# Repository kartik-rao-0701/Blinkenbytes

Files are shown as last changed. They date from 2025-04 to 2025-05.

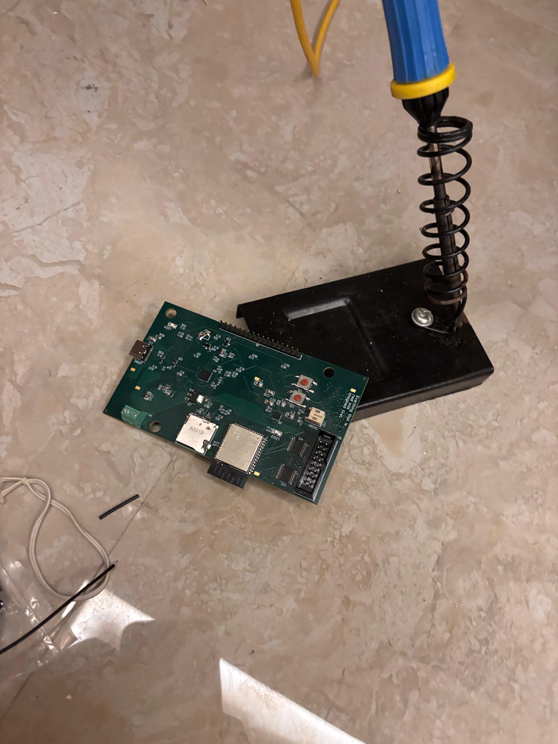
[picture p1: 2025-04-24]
images/pcb after solder.jpg

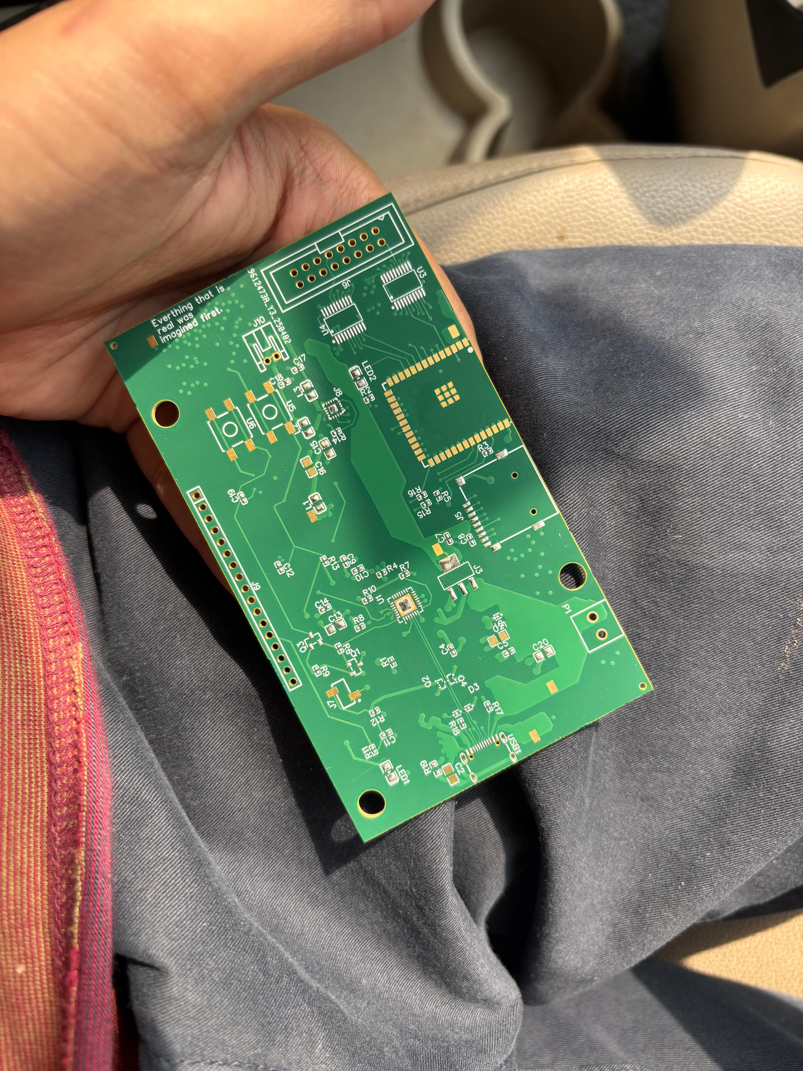
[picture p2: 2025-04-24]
images/pcb recived from jlcpcb(bottom).jpg

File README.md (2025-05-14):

# ESP32-S3 Based Six-Layer Smart Display PCB

This repository contains the design files and documentation for a **custom six-layer PCB** powered by the **ESP32-S3 microcontroller**. The board is designed for advanced **audio-visual applications** with HUB75 LED matrix displays, audio playback, and modern USB-C integration—all packed into a compact, highly optimized board.

---
WhatsApp Image 2025-05-14 at 12 16 19_8cd49088

## 🔧 Key Features

- **ESP32-S3 module** (16MB Flash, 8MB PSRAM *recommended*)
- **Six-layer bare PCB** for enhanced signal stability and thermal performance
- **Onboard microSD card storage** for audio, image, and data assets
- **MAX98357AETE+T I2S Digital Audio Amplifier**
  - Supports up to **8Ω speakers**
  - High-fidelity sound via I2S interface
- **HUB75 LED Matrix Interface**
  - Onboard **HUB75 connector** (16 GPIOs)
  - Optimized for **64x32 and similar RGB matrix panels**
- **USB Type-C (USB 2.1, 16-pin)**
  - First-in-industry integration for **power + UART + expansion**
  - Supports fast prototyping and modern devices
- **UART Bridge using CP2102N-A02-GQFN28R**
  - Compliant with Silicon Labs specs
  - **Errata handled** and resolved
- **Signal Shifting using Nexperia 74AHCT245PW**
  - Shift-register-based level shifter
  - Converts ESP32’s 3.3V signals safely to 5V for HUB75
  - Ensures display stability and reduces ghosting
- **PSRAM Pin Optimization**
  - GPIOs mapped with care
  - ⚠️ *If you need internal PSRAM, remove or reconfigure conflicting components as marked in the schematic*

---

## 🧠 Design Philosophy & Notes

- **Shift registers are used**: Specifically, the **Nexperia 74AHCT245PW** has been chosen for its high-speed performance and compatibility.
- Design is based on **thorough research and technical literature**.
- **No additional multiplexing or daisy-chaining**—this is a **pure GPIO performance** build.
- Crafted for **minimal EMI**, **low signal latency**, and **mechanical robustness**.

---

## 📁 Design Files

- ✅ **EasyEDA and Altium Designer** files included
  - ⚠️ *Altium files are converted* and currently in **beta** — some traces or nets may require manual validation
- ✅ **Bill of Materials (BOM)** file included
WhatsApp Image 2025-05-14 at 12 16 21_1bb49789

---

## 🔌 Power & Connectivity

- **Power input:** USB-C (Recommended: 5V / 5A)
- **UART connection** supported over USB-C via CP2102N
- **HUB75 display power** routed through onboard connector
- **Audio amplifier** powered via dedicated **5V LDO rail**


---

## 🚀 Usage Instructions

1. Flash ESP32-S3 firmware via USB or UART.
2. Connect your HUB75 matrix panel and speaker.
3. Insert your microSD card with the appropriate content.
4. Power up and enjoy visual + audio playback.
5. ⚠️ *If using PSRAM*, check the schematic and remove any components that conflict with PSRAM-designated GPIOs.

---

## 📦 What’s Included

- ✅ Schematic and layout files (EasyEDA + Altium)
- ✅ Bill of Materials (BOM)
- ✅ Documentation of known GPIO conflicts (PSRAM / HUB75 overlap)
- ✅ Sample firmware (optional)

https://github.com/user-attachments/assets/fc8bfb41-cbdd-4a89-a90d-0a03506c137d

## 🔮 Future Plans

- Add capacitive touch buttons
- OTA firmware update support
- Automatic speaker detection
- Battery support and power-saving modes

---

## 📜 License

This project is licensed under the **MIT License**.  
Feel free to **fork**, **modify**, and **contribute** to make it even better!

---

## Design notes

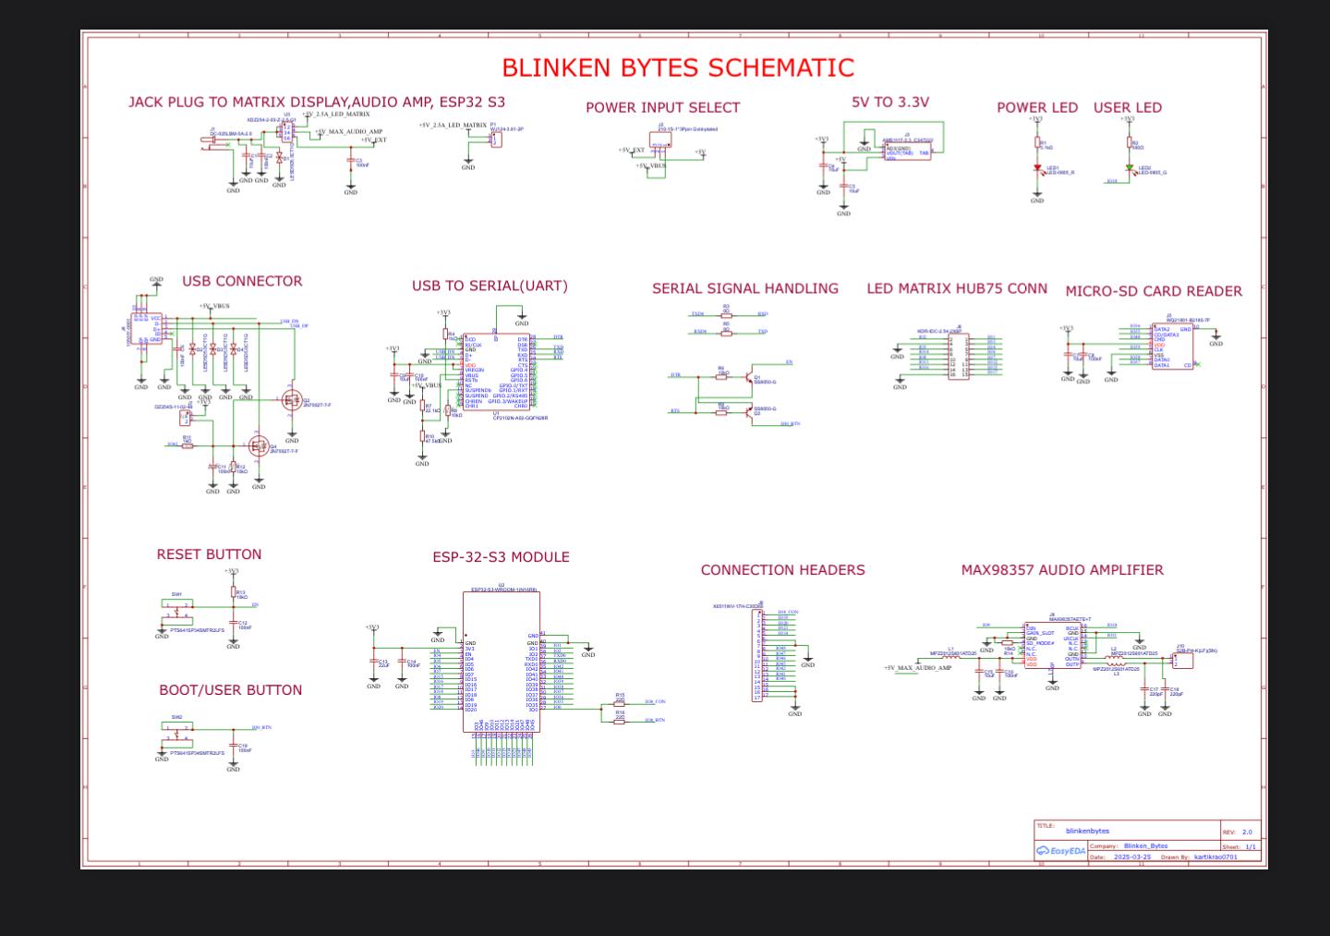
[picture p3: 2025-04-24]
images/schimentics image.jpg

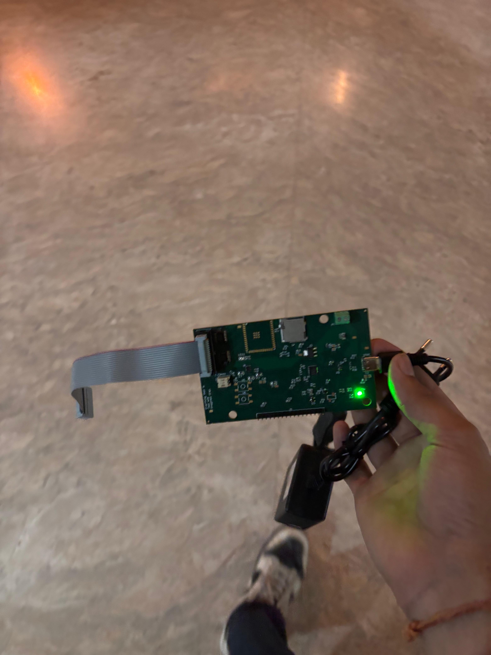
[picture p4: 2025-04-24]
images/pcb without esp-s3 on board.jpg

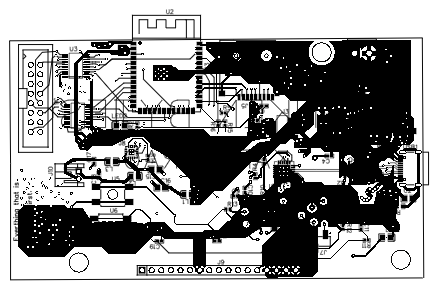
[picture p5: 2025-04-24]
images/PCB_PCB_BLINKENBYTES.png

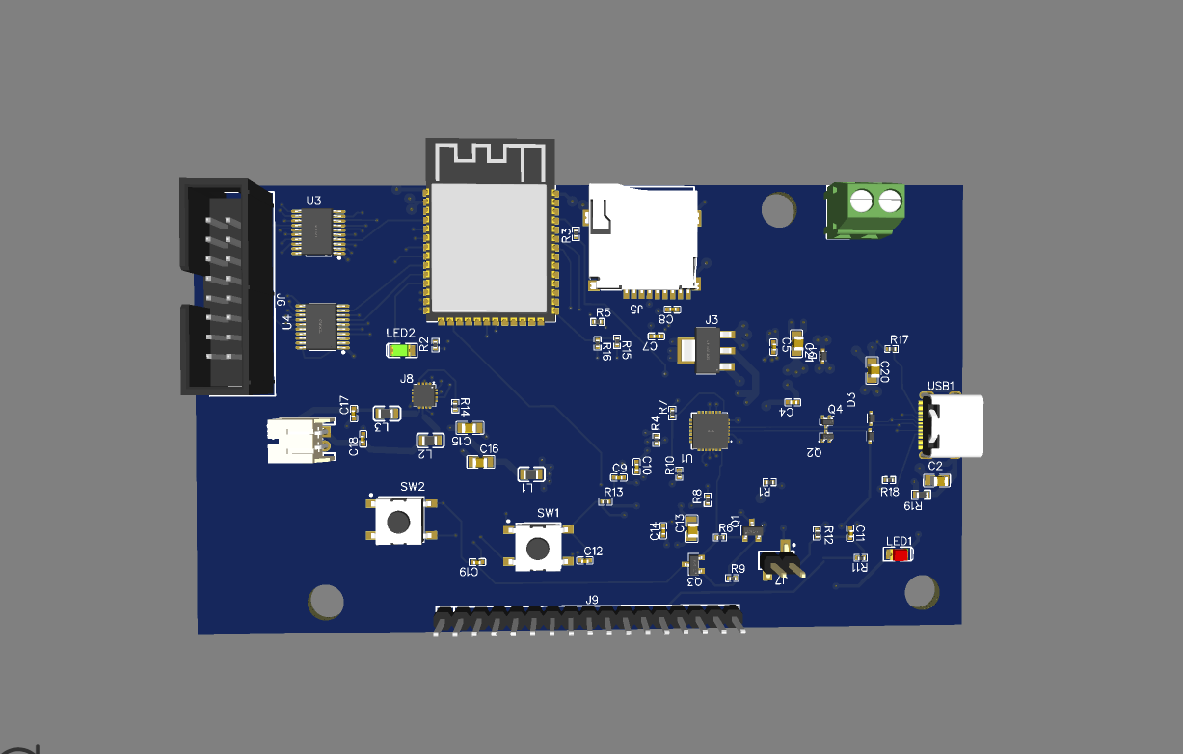
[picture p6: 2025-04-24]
3d_rendered_pcb.png

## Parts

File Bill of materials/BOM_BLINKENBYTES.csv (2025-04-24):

ID | Name | Designator | Footprint | Quantity | Manufacturer Part | Manufacturer | Supplier | Supplier Part | Price | Pins | Contributor | JLCPCB Part Class | link
1 | 100nF | C2,C16,C21 | C0805 | 3 | CL21B104KBFWPJE | SAMSUNG(三星) | LCSC | C6766050 | 0.034 | 2 | lcsc | Extended Part
2 | 10uF | C4,C5,C7,C9 | C0402 | 4 | CL05A106MP5NUNC | SAMSUNG(三星) | LCSC | C315248 | 0.008 | 2 | LCSC | Extended Part
3 | 100nF | C8,C10,C11,C12,C14,C19 | C0402 | 6 | CL05B104KO5NNNC | SAMSUNG(三星) | LCSC | C1525 | 0.001 | 2 |  | Basic Part
4 | 22uF | C13 | C0805 | 1 | CL21A226MAQNNNE | SAMSUNG(三星) | LCSC | C45783 | 0.024 | 2 |  | Basic Part
5 | 10uF | C15,C20 | C0805 | 2 | CL21B106KAYQNNE | SAMSUNG(三星) | LCSC | C3039694 | 0.049 | 2 | lcsc | Extended Part
6 | 220pF | C17,C18 | C0402 | 2 | 04025A221JAT2A | Kyocera AVX | LCSC | C597026 | 0.011 | 2 | LCSC | Extended Part
7 | LESD5D5.0CT1G | D1,D3,D4 | SOD-523_L1.2-W0.8-LS1.6-BI | 3 | LESD5D5.0CT1G | LRC(乐山无线电) | LCSC | C383211 | 0.018 | 2 | LCSC | Extended Part
8 | AMS1117-3.3_C347222 | J3 | SOT-223-4_L6.5-W3.5-P2.30-LS7.0-BR | 1 | AMS1117-3.3 | UMW(友台半导体) | LCSC | C347222 | 0.039 | 4 | LCSC | Extended Part
9 | WQ21801-B2180-7F | J5 | TF-SMD_WQ21801-B2180-7F | 1 | WQ21801-B2180-7F | FOXCONN(富士康) | LCSC | C2836427 | 0.421 | 10 | LCSC
10 | HDR-IDC-2.54-2X8P | J6 | IDC-TH_16P-P2.54_C3406 | 1 | 2.54-2*8P简牛 | BOOMELE(博穆精密) | LCSC | C3406 | 0.097 | 16 |  | Extended Part
11 | DZ254S-11-02-48 | J7 | HDR-SMD_2P-P2.54_XKB_X6511WVS-02H-C60D48R2 | 1 | DZ254S-11-02-48 | DEALON(德艺隆) | LCSC | C5160785 | 0.022 | 2 | lcsc | Extended Part
12 | MAX98357AETE+T | J8 | TQFN-16_L3.0-W3.0-P0.50-BL-EP1.5 | 1 | MAX98357AETE+T | ADI(亚德诺)/MAXIM(美信) | LCSC | C910544 | 2.066 | 17 | LCSC | Extended Part
13 | X6511WV-17H-C30D60 | J9 | HDR-TH_17P-P2.54-V-M | 1 | X6511WV-17H-C60D30 | XKB Connection(中国星坤) | LCSC | C725949 | 0.26 | 17 | LCSC | Extended Part
14 | S2B-PH-K(LF)(SN) | J10 | CONN-TH_S2B-PH-K-LF-SN | 1 | S2B-PH-K(LF)(SN) | JST | LCSC | C265016 | 0.062 | 2 | LCSC | Extended Part
15 | MPZ2012S300ATD25 | L1,L2,L3 | L0805 | 3 | MPZ2012S300ATD25 | TDK | LCSC | C307779 | 0.037 | 2 | LCSC | Extended Part
16 | LED-0805_G | LED1,LED2 | LED0805_GREEN | 2 | NCD0805G1 | 国星光电 |  | C84260 | 0.02 | 2 | LCEDA_Lib
17 | WJ124-3.81-2P | P1 | CONN-TH_2P-P3.81_KF124-3.81-2P | 1 | WJ124-3.81-2P | KANGNEX(康奈克斯电气) | LCSC | C69811 | 0.137 | 2
18 | SS8050-G | Q1,Q3 | SOT-23-3_L2.9-W1.3-P1.90-LS2.4-BR | 2 | SS8050-G(RANGE:120-200) | CJ(江苏长电/长晶) | LCSC | C164886 | 0.016 | 3 | LCSC | Extended Part
19 | 2N7002T-7-F | Q2,Q4 | SOT-523-3_L1.6-W0.8-P1.00-LS1.6-BR | 2 | 2N7002T-7-F | DIODES(美台) | LCSC | C139445 | 0.049 | 3 | LCSC | Extended Part
20 | 5.1kΩ | R1,R17,R18 | R0402 | 3 | 0402WGF5101TCE | UNI-ROYAL(厚声) | LCSC | C25905 | 0.001 | 2 |  | Basic Part
21 | 560Ω | R2 | R0402 | 1 | 0402WGF5600TCE | UNI-ROYAL(厚声) | LCSC | C25126 | 0.001 | 2 |  | Extended Part
22 | 0Ω | R3,R5 | R0402 | 2 | 0402WGF0000TCE | UNI-ROYAL(厚声) | LCSC | C17168 | 0.001 | 2 |  | Basic Part
23 | 1kΩ | R4,R11 | R0402 | 2 | 0402WGF1001TCE | UNI-ROYAL(厚声) | LCSC | C11702 | 0.001 | 2 |  | Basic Part
24 | 10kΩ | R6,R9,R14 | R0402 | 3 | 0402WGF1002TCE | UNI-ROYAL(厚声) | LCSC | C25744 | 0.001 | 2
25 | 22.1kΩ | R7 | R0402 | 1 | 0402WGF2212TCE | UNI-ROYAL(厚声) | LCSC | C43473 | 0.001 | 2 |  | Extended Part
26 | 10kΩ | R8,R12,R13 | R0402 | 3 | 0402WGF1002TCE | UNI-ROYAL(厚声) | LCSC | C25744 | 0.001 | 2 |  | Basic Part
27 | 47.5kΩ | R10 | R0402 | 1 | 0402WGF4752TCE | UNI-ROYAL(厚声) | LCSC | C25896 | 0.001 | 2 |  | Extended Part
28 | 22Ω | R15,R16 | R0402 | 2 | 0402WGF220JTCE | UNI-ROYAL(厚声) | LCSC | C25092 | 0.001 | 2 |  | Basic Part
29 | 10kΩ | R19 | R0603 | 1 | 0603WAF1002T5E | UNI-ROYAL(厚声) | LCSC | C25804 | 0.001 | 2 |  | Basic Part
30 | CP2102N-A02-GQFN28R | U1 | QFN-28_L5.0-W5.0-P0.50-TL-EP3.3 | 1 | CP2102N-A02-GQFN28R | SKYWORKS/SILICON LABS(芯科) | LCSC | C964632 | 1.902 | 29 | LCSC | Extended Part
31 | ESP32-S3-WROOM-1(N8R8) | U2 | WIRELM-SMD_ESP32-S3-WROOM-1 | 1 | ESP32-S3-WROOM-1-N8R8 | ESPRESSIF(乐鑫) | LCSC | C2913201 | 5.398 | 41 | LCSC | Extended Part
32 | 74AHCT245PW,118 | U3,U4 | TSSOP-20_L6.5-W4.4-P0.65-LS6.4-BL | 2 | 74AHCT245PW,118 | Nexperia(安世) | LCSC | C173388 | 0.259 | 20 | LCSC | Extended Part
33 | YTS1S0053BEG00 | U5,U6 | KEY-SMD_4P-L6.4-W6.3-P4.00-LS9.5 | 2 | YTS1S0053BEG00 | YIYUAN(怡远) | LCSC | C5188563 | 0.075 | 4 | lcsc | Extended Part
34 | TYPE-C 16P(073) | USB1 | USB-C-SMD_TYPE-C16PIN_C668624 | 1 | TYPE-C 16P(073) | SHOU HAN(首韩) | LCSC | C668624 | 0.103 | 16 | LCSC | Extended Part

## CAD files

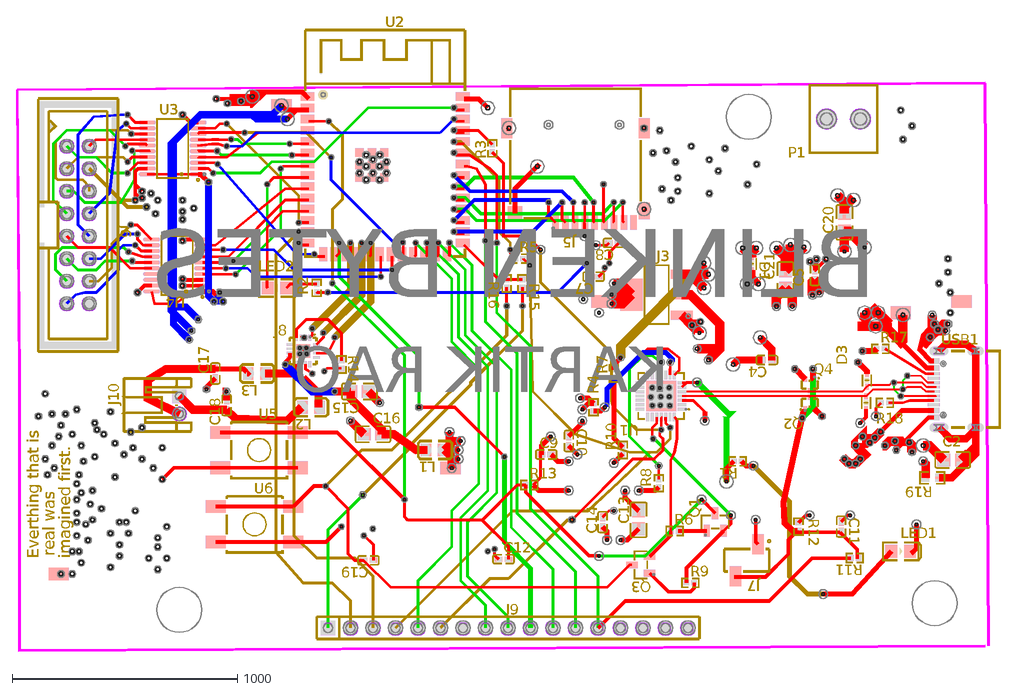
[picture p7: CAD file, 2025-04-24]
pcb/PCB_BLINKENBYTES_autocadfile.dxf
BLINKEN BYTES
KARTIK RAO
Everthing that is
real was
imagined first.
L1
L2
L3
LED1
U2
U5
U6
C20
C21
R17
R18
R19
USB1
R10
C2
C13
C15
C16
C4
C5
C7
C8
C9
C10
C11
C12
C14
C17
C18
C19
D1
D3
J3
J5
J7
J8
J9
J10
LED2
P1
Q1
Q3
Q2
Q4
R1
R2
R3
R4
R5
R6
R7
R8
R9
R11
R12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

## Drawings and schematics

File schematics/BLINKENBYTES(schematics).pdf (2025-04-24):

### GND

+3V3

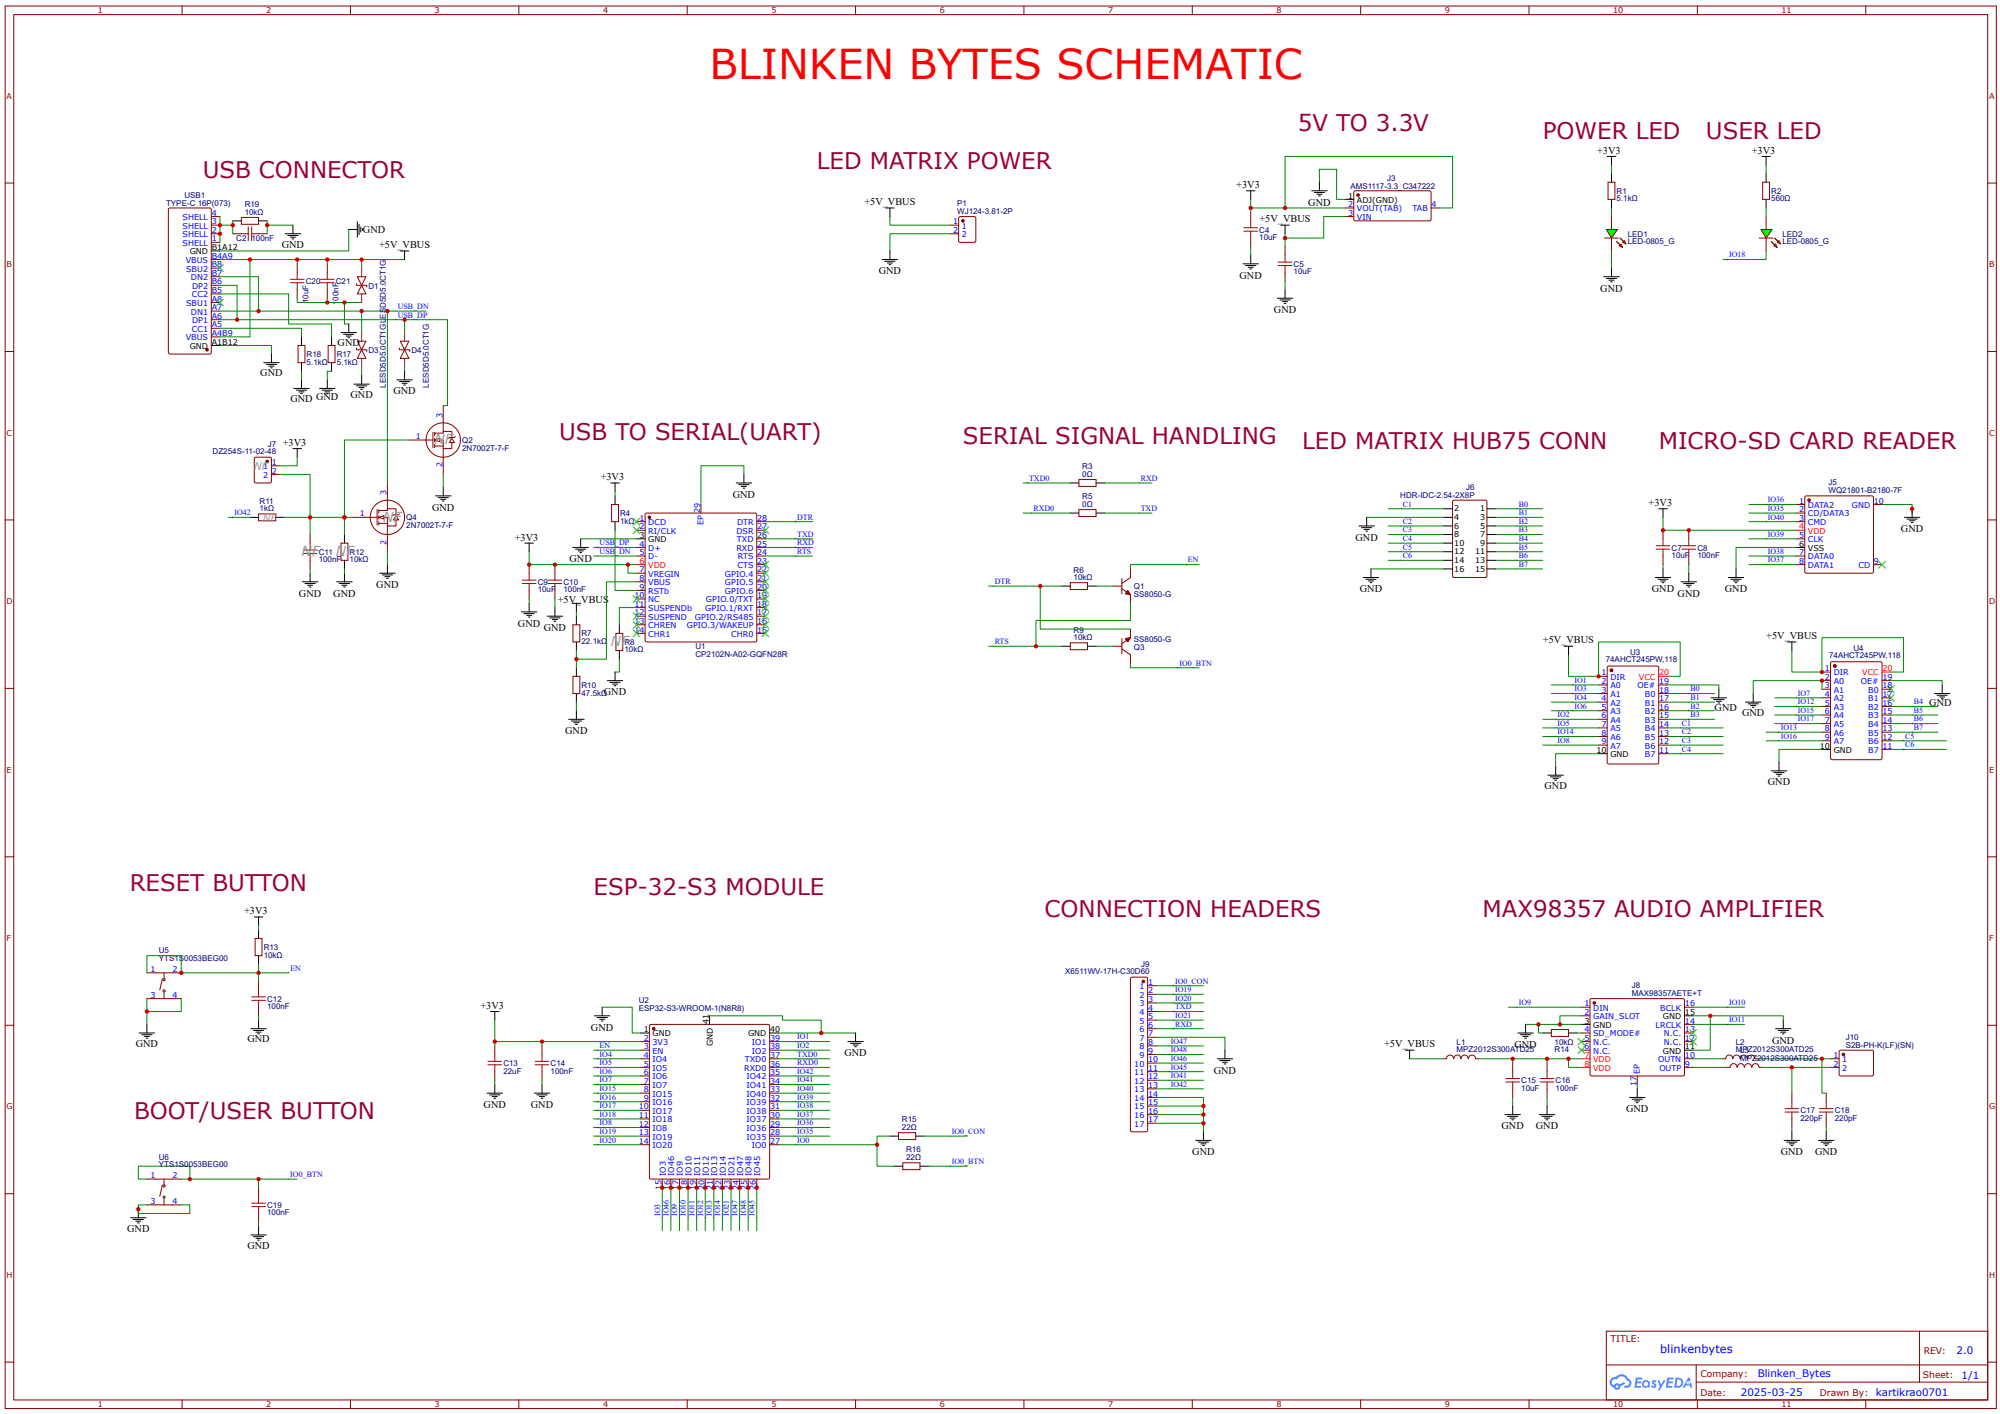
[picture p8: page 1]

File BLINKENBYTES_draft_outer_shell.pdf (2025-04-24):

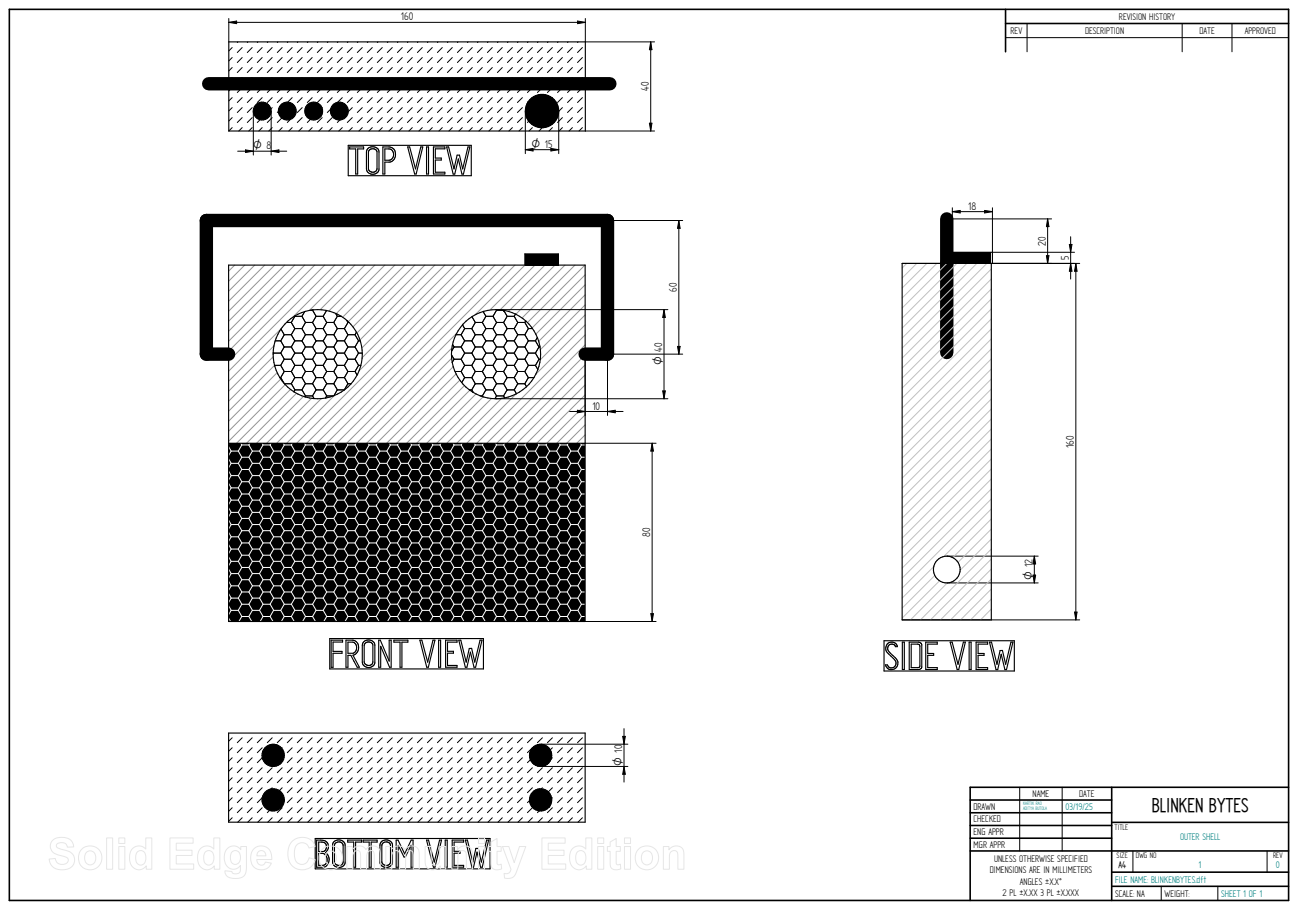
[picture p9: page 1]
TITLE; OUTER SHELL; SCALE: NA; WEIGHT:; SHEET 1 OF 1

160 18 | REVISION HISTORY

REV | DESCRIPTION | DATE | APPROVED

NAME | DATE | BLINKEN BYTES

DRAWN | KARTIK RAO ADITYA BUTOLA | 03/19/25
CHECKED
ENG APPR
MGR APPR
UNLESS OTHERWISE SPECIFIED DIMENSIONS ARE IN MILLIMETERS ANGLES ±X.X° 2 PL ±X.XX 3 PL ±X.XXX | SIZE A4 | DWG NO 1 | REV 0

FILE NAME: BLINKENBYTES.dft

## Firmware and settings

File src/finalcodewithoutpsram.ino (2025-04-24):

/*
 * ESP32-S3 N8R8 Display and Media Center (Optimized for No PSRAM)
 * Features:
 * - Rotary encoder navigation with scrollwheel-like interface
 * - Multiple screens (Time/Date, Weather, Stocks, Bitcoin)
 * - SD card music player with album art display
 * - Radio playback with time-shift capability using SD card buffer
 * - SD card image slideshow with proper orientation
 * - Optimized for ESP32-S3 with 8MB RAM, no PSRAM dependency
 */

#include <ESP32-HUB75-MatrixPanel-I2S-DMA.h>
#include <WiFi.h>
#include <HTTPClient.h>
#include <ArduinoJson.h>
#include <time.h>
#include <ESP32Encoder.h>
#include <SD.h>
#include <SPI.h>
#include <driver/i2s.h>
#include <Audio.h>
#include <JPEGDecoder.h>
#include <JPEGDEC.h>
#include <esp_heap_caps.h>
#include <algorithm>

// ================= LED Matrix Connections =================
#define R1_PIN     1     // Red Row 1
#define G1_PIN     2     // Green Row 1
#define B1_PIN     3     // Blue Row 1
#define R2_PIN     4     // Red Row 2
#define G2_PIN     5     // Green Row 2
#define B2_PIN     6     // Blue Row 2
#define A_PIN      7     // Address line A
#define B_PIN      8     // Address line B
#define C_PIN      12    // Address line C
#define D_PIN      13    // Address line D
#define E_PIN      -1    // Address line E (Only used in 64-row panels)
#define CLK_PIN    15    // Clock pin
#define LAT_PIN    16    // Latch pin
#define OE_PIN     17    // Output Enable

// ================= SD Card Connections =================
#define SD_DATA2   36    // Data2
#define SD_DATA3   35    // CD/Data3
#define SD_CMD     40    // Command
#define SD_CLK     39    // Clock
#define SD_DATA0   38    // Data0
#define SD_DATA1   37    // Data1

// ================= Rotary Encoder Connections =================
#define ENCODER_CLK   18   // CLK pin
#define ENCODER_DT    19   // DT pin
#define ENCODER_SW    20   // Switch (button) pin

// ================= MAX98357 Audio Chip =================
#define I2S_DIN    9     // Digital audio data input
#define I2S_BCLK   10    // Bit clock
#define I2S_LRCLK  11    // Left-right clock

// WiFi credentials
const char* ssid = "kartik's iPhone";
const char* password = "jeiuvbsfgn";

// API Keys
const char* weatherApiKey = "9ad9d95f5fe5ed2ab0ac1c0c6f391dcc";
const char* stockApiKey = "49Y4AEA59RIWSDDW";
const char* lastFmApiKey = "4b1760bb21f92ed72c6e38a55c1cfc7f";

// API Endpoints
const char* weatherServer = "http://api.openweathermap.org/data/2.5/weather?id=1273294&units=metric&appid=9ad9d95f5fe5ed2ab0ac1c0c6f391dcc";
const String stockSymbols[] = {"TSLA", "AAPL", "MSFT", "GOOGL", "AMZN"};
int currentStockIndex = 0;
const int numStocks = 5;

// Bitcoin API
const char* cryptoServer = "https://api.coingecko.com/api/v3/simple/price?ids=bitcoin&vs_currencies=usd&include_24hr_change=true";

// Radio stations in Delhi
const char* radioStations[] = {
    "http://peridot.streamguys.com:7150/Mirchi",
    "http://prclive1.listenon.in:9888/",
    "http://sc-bb.1.fm:8017/",
    "http://airhlspush.pc.cdn.bitgravity.com/airlive/hlspush/hlsmaster/fmaircr_64k.m3u8",
    "http://airhlspush.pc.cdn.bitgravity.com/airlive/hlspush/hlsmaster/fmaircr_64k.m3u8"
};
const char* radioNames[] = {"Radio Mirchi", "Radio City", "Bombay Beats", "AIR Rainbow", "AIR Gold"};
const int numRadioStations = 5;
int currentRadioStation = 0;

// NTP Server for time synchronization
const char* ntpServer = "pool.ntp.org";
long gmtOffset_sec = 19800;  // GMT+5:30 for India
int daylightOffset_sec = 0;

// Matrix Display Configuration
#define PANEL_WIDTH 64
#define PANEL_HEIGHT 32
#define PANEL_CHAIN 1
#define MATRIX_ROTATION 0

// Define HUB75 pin mappings for ESP32-S3
HUB75_I2S_CFG::i2s_pins pins = {
    R1_PIN, G1_PIN, B1_PIN, R2_PIN, G2_PIN, B2_PIN, 
    A_PIN, B_PIN, C_PIN, D_PIN, E_PIN, 
    LAT_PIN, OE_PIN, CLK_PIN
};

HUB75_I2S_CFG mxconfig(PANEL_WIDTH, PANEL_HEIGHT, PANEL_CHAIN, pins);
MatrixPanel_I2S_DMA* display = nullptr;

// I2S configuration for audio
i2s_config_t i2s_config = {
    .mode = (i2s_mode_t)(I2S_MODE_MASTER | I2S_MODE_TX),
    .sample_rate = 44100,
    .bits_per_sample = I2S_BITS_PER_SAMPLE_16BIT,
    .channel_format = I2S_CHANNEL_FMT_RIGHT_LEFT,
    .communication_format = I2S_COMM_FORMAT_STAND_I2S,
    .intr_alloc_flags = ESP_INTR_FLAG_LEVEL1,
    .dma_buf_count = 8,
    .dma_buf_len = 64,
    .use_apll = false,
    .tx_desc_auto_clear = true,
    .fixed_mclk = 0
};

i2s_pin_config_t i2s_pins = {
    .bck_io_num = I2S_BCLK,
    .ws_io_num = I2S_LRCLK,
    .data_out_num = I2S_DIN,
    .data_in_num = -1
};

// Audio objects
Audio audio;

// Rotary encoder setup
ESP32Encoder encoder;
int lastEncoderValue = 0;
bool buttonPressed = false;
long lastButtonPress = 0;
bool doubleClickDetected = false;
unsigned long lastSingleClickTime = 0;

// Menu system
#define MENU_HOME 0
#define MENU_CLOCK 1
#define MENU_WEATHER 2
#define MENU_STOCKS 3
#define MENU_CRYPTO 4
#define MENU_RADIO 5
#define MENU_MUSIC 6
#define MENU_SLIDESHOW 7

int mainMenuPosition = 0;
int submenuPosition = 0;
bool inSubmenu = false;
bool inScrollAnimation = false;
bool audioPlaying = false;
bool radioPlaying = false;
bool musicPlaying = false;
bool slideshowActive = false;
bool musicNavigationMode = false;

// Data structures
struct WeatherData {
    float temp;
    float feels_like;
    int humidity;
    String description;
    String icon;
    String city;
} currentWeather;

struct StockData {
    String symbol;
    float price;
    float change;
    float change_percent;
    float prices[10];
} stocks[5];

struct CryptoData {
    float price;
    float change_24h;
} bitcoin;

// Radio buffer settings - OPTIMIZED FOR LESS MEMORY
#define RADIO_BUFFER_MINUTES 2  // Reduced from 10 to save memory
#define BUFFER_CHUNK_SIZE 4096  // Reduced from 32768
bool timeShiftActive = false;
int timeShiftOffset = 0;
String currentSong = "Unknown";
String currentArtist = "Unknown";

// Music player variables - REDUCED ARRAY SIZES
#define MAX_SONGS 50       // Reduced from 100
#define MAX_IMAGES 25      // Reduced from 50
String musicFiles[MAX_SONGS];
String musicArtFiles[MAX_SONGS];
int musicCount = 0;
int currentMusic = 0;
String currentMusicTitle = "Unknown";
String currentMusicArtist = "Unknown";
String currentMusicAlbum = "Unknown";
String currentAlbumArtPath = "";
int musicVolume = 15;

// Slideshow variables
String imageFiles[MAX_IMAGES];
int imageCount = 0;
int currentImage = 0;
unsigned long lastImageChange = 0;
const unsigned long imageChangeInterval = 5000;

// Animation variables
unsigned long lastFrameTime = 0;
const int frameDelay = 50;
int scrollOffset = 0;
bool transitioning = false;
int targetScreen = 0;
int currentScreen = 0;
int scrollWheelPosition = 0;
int scrollWheelTargetPosition = 0;
bool scrollWheelAnimating = false;

// Update intervals
unsigned long lastWeatherUpdate = 0;
unsigned long lastStockUpdate = 0;
unsigned long lastCryptoUpdate = 0;
unsigned long lastTimeUpdate = 0;
const unsigned long weatherInterval = 300000;
const unsigned long stockInterval = 300000;
const unsigned long cryptoInterval = 180000;
const unsigned long timeUpdateInterval = 1000;

// SD Card buffer for radio time-shift
File radioBufferFile;
int currentBufferIndex = 0;
const int maxBufferFiles = RADIO_BUFFER_MINUTES * 6;
String radioBufferFiles[RADIO_BUFFER_MINUTES * 6];
unsigned long lastBufferWrite = 0;
const unsigned long bufferWriteInterval = 10000;

// Weather icons (5x5 pixels)
const uint16_t SUNNY_ICON[] = {
    0, 0xFFE0, 0, 0, 0,
    0xFFE0, 0xFFE0, 0xFFE0, 0, 0,
    0, 0xFFE0, 0xFFE0, 0xFFE0, 0,
    0, 0, 0xFFE0, 0xFFE0, 0xFFE0,
    0, 0, 0, 0xFFE0, 0
};

const uint16_t CLOUDY_ICON[] = {
    0, 0xFFFF, 0xFFFF, 0, 0,
    0xFFFF, 0xFFFF, 0xFFFF, 0xFFFF, 0,
    0, 0xFFFF, 0xFFFF, 0xFFFF, 0xFFFF,
    0, 0, 0xFFFF, 0xFFFF, 0xFFFF,
    0, 0, 0, 0, 0
};

const uint16_t RAINY_ICON[] = {
    0, 0xFFFF, 0xFFFF, 0, 0,
    0xFFFF, 0xFFFF, 0xFFFF, 0xFFFF, 0,
    0, 0x001F, 0xFFFF, 0x001F, 0xFFFF,
    0, 0, 0x001F, 0, 0x001F,
    0, 0x001F, 0, 0, 0
};

// Menu wheel items
const char* mainMenuItems[] = {
    "Clock", "Weather", "Stocks", "Bitcoin", "Radio", "Music", "Slideshow"
};
const int numMainMenuItems = 7;

// JPEG decoder for album art
JPEGDEC jpeg;

// Function to check available memory
bool checkMemory(size_t requiredSize) {
    size_t freeHeap = ESP.getFreeHeap();
    if (freeHeap < requiredSize) {
        // Display low memory warning
        display->fillRect(0, 0, PANEL_WIDTH, 8, 0);  // Clear top line
        display->setTextSize(1);
        display->setCursor(2, 1);
        display->setTextColor(display->color565(255, 0, 0));
        display->print("Low Mem: ");
        display->print(freeHeap / 1024);
        display->print("kB");
        return false;
    }
    return true;
}
#ifndef PI
#define PI 3.14159265358979323846
#endif
// Function prototypes
void fetchWeather();
void fetchStockData(int index);
void fetchBitcoinData();
void displayTime();
void displayWeather();
void displayStock(int index);
void displayCrypto();
void displayRadioMenu();
void displayRadioPlayer();
void displayMusicMenu();
void displayMusicPlayer();
void displaySlideshow();
void drawWeatherIcon(String iconCode, int x, int y);
void drawStockChart(StockData stock, int x, int y, int width, int height);
void handleEncoder();
void handleButton();
void showLoadingScreen(String message);
void drawScreenContent(int screen, int offset);
void updateDisplay();
void initSDCard();
void scanSDCardImages();
void scanSDCardMusic();
void loadAlbumArt(int songIndex);
void initAudio();
void startRadio(int stationIndex);
void stopRadio();
void startTimeShift(int secondsBack);
void stopTimeShift();
void playMusic(int songIndex);
void stopMusic();
void nextMusic();
void prevMusic();
void playTickSound();
void drawScrollWheel(int position);
void animateScrollWheel();
void showMenuTransition(int fromItem, int toItem);
void initRadioBuffer();
void writeToRadioBuffer(uint8_t* buffer, size_t size);
void readFromRadioBuffer(int timeOffset);
String getMusicFileTitle(String filename);
String getMusicFileArtist(String filename);
bool loadJpegFromSD(String filename);
bool loadBmpFromSD(String filename);
int drawMCUblockCallback(JPEGDRAW* pDraw);
String URLEncode(const char* msg);
void checkSystemMemory();


void setup() {
    // Initialize rotary encoder
    encoder.attachHalfQuad(ENCODER_CLK, ENCODER_DT);
    encoder.setCount(0);
    
    // Set up button pin
    pinMode(ENCODER_SW, INPUT_PULLUP);
    
    // Initialize display
    display = new MatrixPanel_I2S_DMA(mxconfig);
    display->begin();
    display->setBrightness8(100);
    display->clearScreen();
    display->setRotation(MATRIX_ROTATION);
    
    // Initialize SD Card
    showLoadingScreen("Init SD Card...");
    initSDCard();
    
    // Set up directories if needed
    if (!SD.exists("/album_art")) {
        SD.mkdir("/album_art");
    }
    
    if (!SD.exists("/radio_buffer")) {
        SD.mkdir("/radio_buffer");
    }
    
    if (!SD.exists("/images")) {
        SD.mkdir("/images");
    }
    
    if (!SD.exists("/music")) {
        SD.mkdir("/music");
    }
    
    // Scan for images in SD card
    scanSDCardImages();
    
    // Scan for music in SD card
    scanSDCardMusic();
    
    // Initialize the radio buffer system
    initRadioBuffer();
    
    // Initialize audio
    showLoadingScreen("Setting up Audio...");
    initAudio();
    
    // Show loading message
    showLoadingScreen("Connecting to WiFi...");
    
    // Connect to WiFi
    WiFi.begin(ssid, password);
    int wifiAttempts = 0;
    while (WiFi.status() != WL_CONNECTED && wifiAttempts < 20) {
        delay(500);
        wifiAttempts++;
        display->drawPixel(10 + wifiAttempts, 20, display->color565(0, 255, 0));
        display->fillRect(10, 20, wifiAttempts, 1, display->color565(0, 255, 0));
    }
    
    if (WiFi.status() == WL_CONNECTED) {
        // Synchronize time
        showLoadingScreen("Syncing Time...");
        configTime(gmtOffset_sec, daylightOffset_sec, ntpServer);
        
        // Initial data fetch
        showLoadingScreen("Fetching Weather...");
        fetchWeather();
        
        showLoadingScreen("Fetching Stocks...");
        for (int i = 0; i < numStocks; i++) {
            fetchStockData(i);
            delay(300); // Avoid rate limiting
        }
        
        showLoadingScreen("Fetching Bitcoin...");
        fetchBitcoinData();
    } else {
        showLoadingScreen("WiFi Failed!");
        delay(2000);
    }
    
    // Ready!
    showLoadingScreen("Welcome!");
    delay(500);
    
    // Start with clock display
    currentScreen = MENU_CLOCK;
    mainMenuPosition = 0;
}

void loop() {
    // Update data at regular intervals
    unsigned long currentMillis = millis();
    
    // Check system memory periodically
    if (currentMillis % 5000 == 0) {
        checkSystemMemory();
    }
    
    if (WiFi.status() == WL_CONNECTED) {
        if (currentMillis - lastWeatherUpdate > weatherInterval) {
            fetchWeather();
            lastWeatherUpdate = currentMillis;
        }
        
        if (currentMillis - lastStockUpdate > stockInterval) {
            fetchStockData(currentStockIndex);
            currentStockIndex = (currentStockIndex + 1) % numStocks;
            lastStockUpdate = currentMillis;
        }
        
        if (currentMillis - lastCryptoUpdate > cryptoInterval) {
            fetchBitcoinData();
            lastCryptoUpdate = currentMillis;
        }
    }
    
    if (currentMillis - lastTimeUpdate > timeUpdateInterval) {
        lastTimeUpdate = currentMillis;
    }
    
    // Handle radio buffer
    if (radioPlaying && !timeShiftActive && currentMillis - lastBufferWrite > bufferWriteInterval) {
        lastBufferWrite = currentMillis;
    }
    
    // Handle slideshow timing
    if (slideshowActive && imageCount > 0 && currentMillis - lastImageChange > imageChangeInterval) {
        currentImage = (currentImage + 1) % imageCount;
        lastImageChange = currentMillis;
    }
    
    // Process audio data
    if (radioPlaying || musicPlaying) {
        audio.loop();
    }
    
    // Handle encoder input
    handleEncoder();
    handleButton();
    
    // Handle scroll wheel animation
    if (scrollWheelAnimating) {
        animateScrollWheel();
    }
    
    // Update display
    if (currentMillis - lastFrameTime > frameDelay) {
        updateDisplay();
        lastFrameTime = currentMillis;
    }
}

void checkSystemMemory() {
    if (ESP.getFreeHeap() < 3000) { // Critical low memory
        // Emergency recovery - stop memory-intensive operations
        if (musicPlaying) stopMusic();
        if (radioPlaying) stopRadio();
        slideshowActive = false;
        
        // Reset to clock display
        inSubmenu = false;
        currentScreen = MENU_CLOCK;
        
        // Show warning
        display->fillScreen(0);
        display->setTextSize(1);
        display->setCursor(5, 10);
        display->setTextColor(display->color565(255, 0, 0));
        display->print("MEMORY LOW");
        display->setCursor(5, 20);
        display->print("Resetting...");
        delay(2000);
    }
}

void initSDCard() {
    SPI.begin(SD_CLK, SD_DATA0, SD_CMD, SD_DATA3);
    SD.begin(SD_DATA3);
}

void initRadioBuffer() {
    // Clear any existing buffer files
    File dir = SD.open("/radio_buffer");
    if (dir && dir.isDirectory()) {
        File file = dir.openNextFile();
        while (file) {
            String fileName = String(file.name());
            file.close();
            SD.remove("/radio_buffer/" + fileName);
            file = dir.openNextFile();
        }
    }
    dir.close();
    
    // Initialize buffer file array
    for (int i = 0; i < maxBufferFiles; i++) {
        radioBufferFiles[i] = "/radio_buffer/chunk_" + String(i) + ".buf";
    }
    
    currentBufferIndex = 0;
}

// OPTIMIZED: Write to radio buffer in smaller chunks
void writeToRadioBuffer(uint8_t* buffer, size_t size) {
    if (!radioPlaying || timeShiftActive) return;
    
    // Check available memory before proceeding
    if (ESP.getFreeHeap() < size + 4000) { // 4KB safety margin
        return; // Skip buffer writing if memory is low
    }
    
    // Open the current buffer file
    radioBufferFile = SD.open(radioBufferFiles[currentBufferIndex], FILE_WRITE);
    if (!radioBufferFile) {
        return;
    }
    
    // Write in smaller chunks if necessary
    const size_t MAX_WRITE = 1024; // 1KB chunks
    size_t bytesLeft = size;
    size_t offset = 0;
    
    while (bytesLeft > 0) {
        size_t bytesToWrite = (bytesLeft > MAX_WRITE) ? MAX_WRITE : bytesLeft;
        radioBufferFile.write(buffer + offset, bytesToWrite);
        bytesLeft -= bytesToWrite;
        offset += bytesToWrite;
        
        // Small yield to avoid watchdog trigger
        yield();
    }
    
    radioBufferFile.close();
    
    // Move to the next buffer file
    currentBufferIndex = (currentBufferIndex + 1) % maxBufferFiles;
    
    // Initialize the next file (overwrite if it exists)
    if (SD.exists(radioBufferFiles[currentBufferIndex])) {
        SD.remove(radioBufferFiles[currentBufferIndex]);
    }
}

// OPTIMIZED: Read from radio buffer in smaller chunks
void readFromRadioBuffer(int timeOffset) {
    if (!radioPlaying) return;
    
    // Calculate which buffer file to read from
    int fileIndex = (currentBufferIndex - (timeOffset / 10) + maxBufferFiles) % maxBufferFiles;
    
    // Open the file for reading
    radioBufferFile = SD.open(radioBufferFiles[fileIndex], FILE_READ);
    if (!radioBufferFile) {
        return;
    }
    
    // Read buffer in smaller chunks directly to audio output
    const size_t READ_CHUNK = 1024;
    uint8_t* audioChunk = (uint8_t*)malloc(READ_CHUNK);
    
    if (!audioChunk) {
        radioBufferFile.close();
        return;
    }
    
    // Stop current audio playback
    if (audioPlaying) {
        audio.stopSong();
        delay(50);
    }
    
    // In real implementation, you would feed these chunks to audio
    size_t bytesRead;
    while ((bytesRead = radioBufferFile.read(audioChunk, READ_CHUNK)) > 0) {
        // Process audio chunk here
        // audio.processBuffer(audioChunk, bytesRead);
        
        // Small yield to avoid watchdog trigger
        yield();
    }
    
    free(audioChunk);
    radioBufferFile.close();
}

// OPTIMIZED: Prioritize BMP files and limit memory usage
void scanSDCardImages() {
    File root = SD.open("/images");
    if (!root || !root.isDirectory()) {
        return;
    }
    
    File file = root.openNextFile();
    imageCount = 0;
    
    // First pass: collect only BMP files (less memory intensive)
    while (file && imageCount < MAX_IMAGES) {
        String fileName = file.name();
        if (fileName.endsWith(".bmp")) {
            imageFiles[imageCount] = "/images/" + fileName;
            imageCount++;
        }
        file = root.openNextFile();
    }
    
    // Second pass: add JPG files only if we haven't reached MAX_IMAGES
    if (imageCount < MAX_IMAGES) {
        root.rewindDirectory();
        file = root.openNextFile();
        while (file && imageCount < MAX_IMAGES) {
            String fileName = file.name();
            if ((fileName.endsWith(".jpg") || fileName.endsWith(".jpeg")) && !fileName.startsWith("._")) {
                imageFiles[imageCount] = "/images/" + fileName;
                imageCount++;
            }
            file = root.openNextFile();
        }
    }
    
    root.close();
}

void scanSDCardMusic() {
    File root = SD.open("/music");
    if (!root || !root.isDirectory()) {
        return;
    }
    
    File file = root.openNextFile();
    musicCount = 0;
    
    while (file && musicCount < MAX_SONGS) {
        String fileName = file.name();
        if (fileName.endsWith(".mp3") || fileName.endsWith(".wav") || fileName.endsWith(".aac")) {
            musicFiles[musicCount] = "/music/" + fileName;
            
            // Look for a matching BMP album art file with the same name
            String artFilename = fileName.substring(0, fileName.lastIndexOf('.')) + ".bmp";
            String artPath = "/music/" + artFilename;
            if (SD.exists(artPath)) {
                musicArtFiles[musicCount] = artPath;
            } else {
                musicArtFiles[musicCount] = "";
            }
            
            musicCount++;
        }
        file = root.openNextFile();
    }
    
    root.close();
}

void initAudio() {
    audio.setPinout(I2S_BCLK, I2S_LRCLK, I2S_DIN);
    audio.setVolume(musicVolume);
}

String getMusicFileTitle(String filename) {
    // Remove path if present
    int lastSlash = filename.lastIndexOf('/');
    if (lastSlash >= 0) {
        filename = filename.substring(lastSlash + 1);
    }
    
    // Remove extension
    int lastDot = filename.lastIndexOf('.');
    if (lastDot >= 0) {
        filename = filename.substring(0, lastDot);
    }
    
    // Get title part (before _by_)
    int byPos = filename.indexOf("_by_");
    if (byPos >= 0) {
        String title = filename.substring(0, byPos);
        title.replace('_', ' ');
        return title;
    }
    
    String result = filename;
    result.replace('_', ' ');
    return result;
}

String getMusicFileArtist(String filename) {
    // Remove path if present
    int lastSlash = filename.lastIndexOf('/');
    if (lastSlash >= 0) {
        filename = filename.substring(lastSlash + 1);
    }
    
    // Remove extension
    int lastDot = filename.lastIndexOf('.');
    if (lastDot >= 0) {
        filename = filename.substring(0, lastDot);
    }
    
    // Get artist part (after _by_)
    int byPos = filename.indexOf("_by_");
    if (byPos >= 0) {
        String artist = filename.substring(byPos + 4);
        artist.replace('_', ' ');
        return artist;
    }
    
    return "Unknown";
}
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

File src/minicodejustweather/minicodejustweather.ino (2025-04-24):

#include <ESP32-HUB75-MatrixPanel-I2S-DMA.h>
#include <ESP32-VirtualMatrixPanel-I2S-DMA.h>
#include <WiFi.h>
#include <HTTPClient.h>
#include <ArduinoJson.h>

// ===== Panel Configuration =====
#define PANEL_WIDTH     64
#define PANEL_HEIGHT    32
#define PANEL_CHAIN     1

HUB75_I2S_CFG mxconfig(
  PANEL_WIDTH,
  PANEL_HEIGHT,
  PANEL_CHAIN
);
MatrixPanel_I2S_DMA* dma_display = nullptr;

// ===== Wi-Fi & Weather API Config =====
const char* ssid = "NSUT_WIFI";
const char* password = "";
const String apiKey = "9ad9d95f5fe5ed2ab0ac1c0c6f391dcc";
const String city = "Delhi";
const String units = "metric"; // "imperial" for Fahrenheit

void setup() {
  Serial.begin(115200);

  // Set up Matrix Pins
  mxconfig.gpio.r1 = 4;
  mxconfig.gpio.g1 = 5;
  mxconfig.gpio.b1 = 6;
  mxconfig.gpio.r2 = 7;
  mxconfig.gpio.g2 = 15;
  mxconfig.gpio.b2 = 16;
  mxconfig.gpio.a = 17;
  mxconfig.gpio.b = 18;
  mxconfig.gpio.c = 8;
  mxconfig.gpio.d = 3;
  mxconfig.gpio.e = -1;
  mxconfig.gpio.lat = 20;
  mxconfig.gpio.oe = 2;
  mxconfig.gpio.clk = 19;

  dma_display = new MatrixPanel_I2S_DMA(mxconfig);
  dma_display->begin();
  dma_display->clearScreen();

  // Connect to Wi-Fi
  WiFi.begin(ssid, password);
  dma_display->fillScreenRGB888(0, 0, 0);
  dma_display->setTextColor(dma_display->color565(255, 255, 0));
  dma_display->setCursor(0, 0);
  dma_display->print("WiFi...");
  while (WiFi.status() != WL_CONNECTED) {
    delay(500);
    Serial.print(".");
  }

  dma_display->fillScreenRGB888(0, 0, 0);
  dma_display->setTextColor(dma_display->color565(0, 255, 0));
  dma_display->setCursor(0, 0);
  dma_display->print("Connected");

  delay(1000);
  fetchAndDisplayWeather();
}

void loop() {
  // Refresh weather every 10 minutes
  fetchAndDisplayWeather();
  delay(10 * 60 * 1000);
}

void fetchAndDisplayWeather() {
  String url = "http://api.openweathermap.org/data/2.5/weather?q=" + city + "&appid=" + apiKey + "&units=" + units;

  HTTPClient http;
  http.begin(url);
  int httpCode = http.GET();

  if (httpCode > 0) {
    String payload = http.getString();
    DynamicJsonDocument doc(1024);
    deserializeJson(doc, payload);

    float temp = doc["main"]["temp"];
    const char* condition = doc["weather"][0]["main"];

    Serial.printf("Temp: %.1f, Condition: %s\n", temp, condition);

    dma_display->fillScreenRGB888(0, 0, 0); // Clear screen

    // Display temperature
    char tempStr[16];
    sprintf(tempStr, "%.1f C", temp);
    dma_display->setTextColor(dma_display->color565(0, 255, 255));
    dma_display->setCursor(0, 0);
    dma_display->print(tempStr);

    // Display condition
    dma_display->setTextColor(dma_display->color565(255, 255, 0));
    dma_display->setCursor(0, 10);
    dma_display->print(String(condition).substring(0, 10));
  } else {
    dma_display->fillScreenRGB888(0, 0, 0);
    dma_display->setTextColor(dma_display->color565(255, 0, 0));
    dma_display->setCursor(0, 0);
    dma_display->print("HTTP error");
    Serial.println("Failed to fetch weather");
  }

  http.end();
}
